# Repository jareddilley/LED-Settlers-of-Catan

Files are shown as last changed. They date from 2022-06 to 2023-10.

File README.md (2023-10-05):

# SMART-Catan-Game-Board


Fully 3D printed 2-4 person Catan board with corresponding LED tiles, electronic rolling with place pointers, recourse summary display, and all in a battery-powered sealed package. This project is powered by a rechargeable 9V battery and an Arduino nano to minimize its footprint. Above is a demo of the rolling animation that is done at the touch of a button. When clicked a random number generator is used to roll the dice with the same probability of rolling numbers that two regular dice do. Once rolled the number will be displayed on the seven-segment display and the corresponding locations will be singled out and lit up. This fixes one of the common issues of Catan where you roll the dice and try to figure out who gets what.

Built with the Open Source mindset allowing other people to build it at home with a 3D printer (I used an Ender 3 Pro) with a choice of soldier or using a breadboard. 

Attached is the Fusion 360 so the models can be edited directly and used to better understand how it is broken down. A YouTube link for visual learners: https://www.youtube.com/watch?v=NJuYirOUeOg&t=12s&ab_channel=JaredDilley

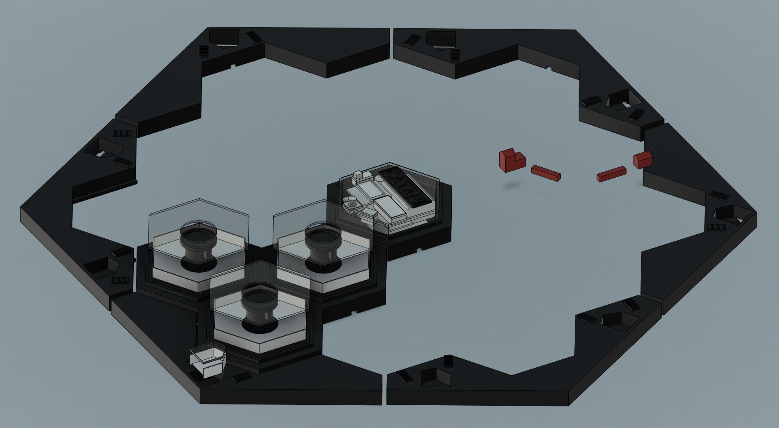
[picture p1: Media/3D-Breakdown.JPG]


Below is the full Arduino schematic for anyone trying to build the project. For those who want a closer look, the diagram can be found in the Fritzing Schematic folder. If there are any confusions feel free to ask in the discussion.

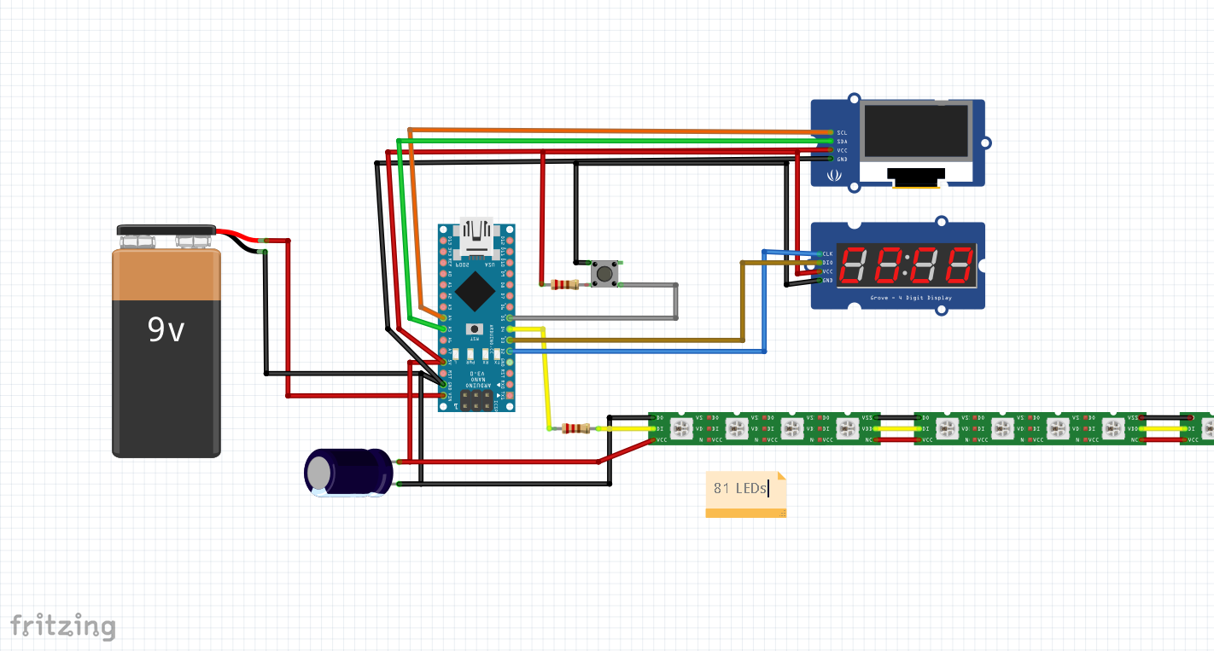
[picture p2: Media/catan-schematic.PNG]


# Board Generation


When the board is powered on the tiles are randomly set up in an instant. I know some people like to play an evenly distributed board, but it can be added as a feature in the second version. The instant setup of the board was the main issue I wanted to fix with this project. Whenever you want to play a game of Catan it always takes time to set up the board. Here it can be set up instantly with the flick of a switch.

# Info Display


With the Arduino micro powering the board I figured I would add additional info that can be tracked on displays. In the middle of the board lies the power center that doubles as the desert tile. Here you can find a seven-segment display that serves as a remembrance for what was previously rolled to the next player. In V2 this could also serve as a time for those who take too long on their turn. In addition, there sits an OLED display that stores the number of rolls that each resource has been rolled. This can help judge the board for what resources might be in short supply and makes for cool stats to look at, at the end of the game. 



# Bonus


The light-up hexagons make a game night in the dark that much cooler.

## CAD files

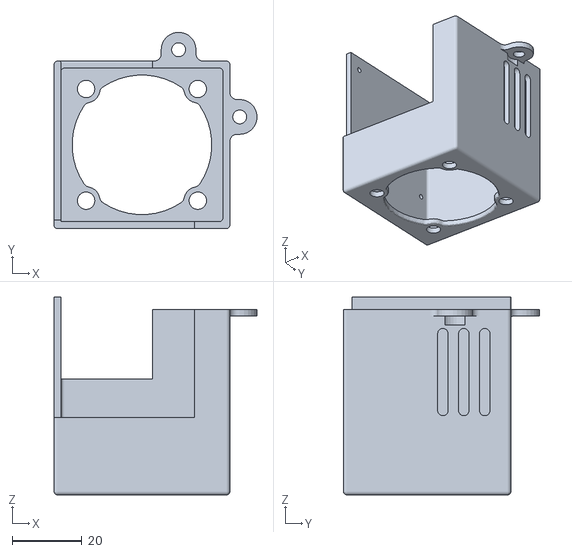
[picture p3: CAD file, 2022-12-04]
Print files/V2.stl
58.2 x 56.2 x 56.7

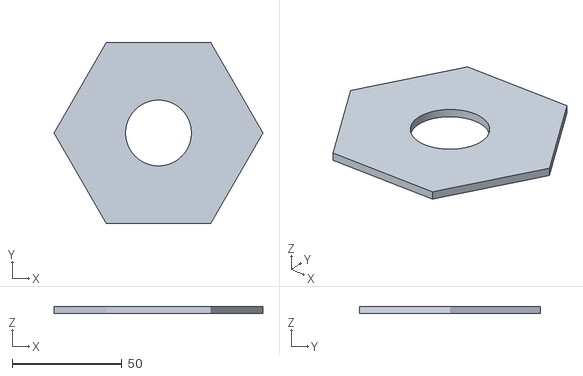
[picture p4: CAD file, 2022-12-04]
Print files/Diffuser Panel.stl
95.2 x 82.5 x 3.17

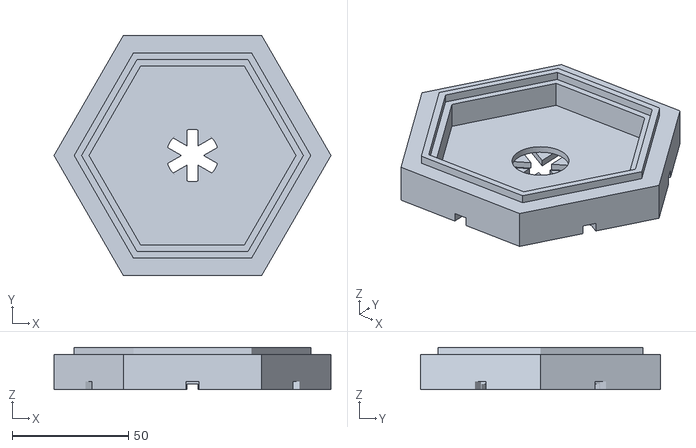
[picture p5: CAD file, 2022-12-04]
Print files/Split Board v2.stl
118.9 x 103.0 x 18.2

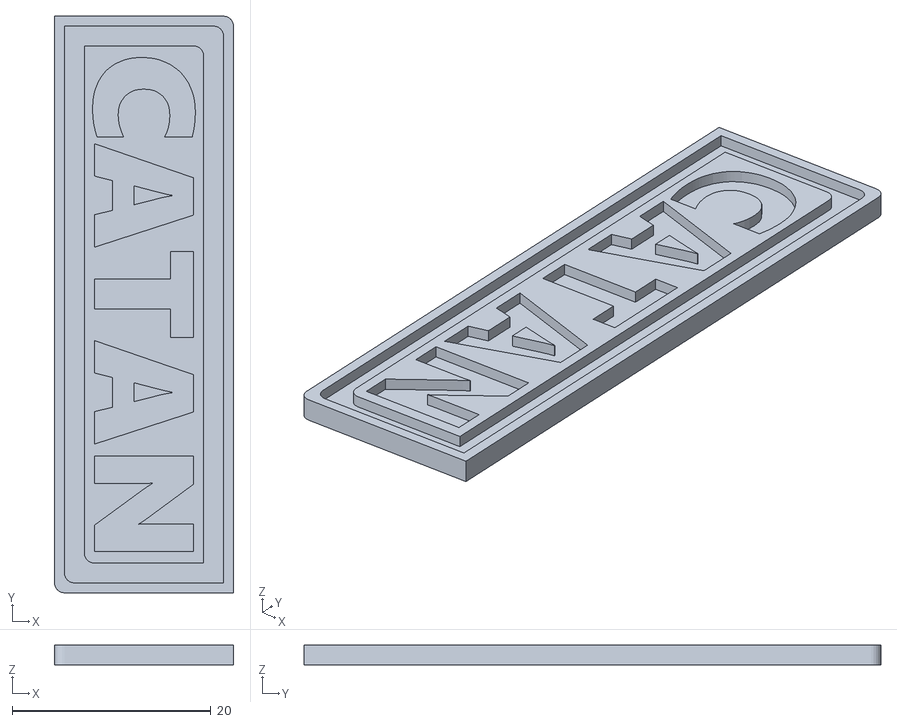
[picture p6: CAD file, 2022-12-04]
Print files/Decal.stl
18.0 x 58.0 x 2.00

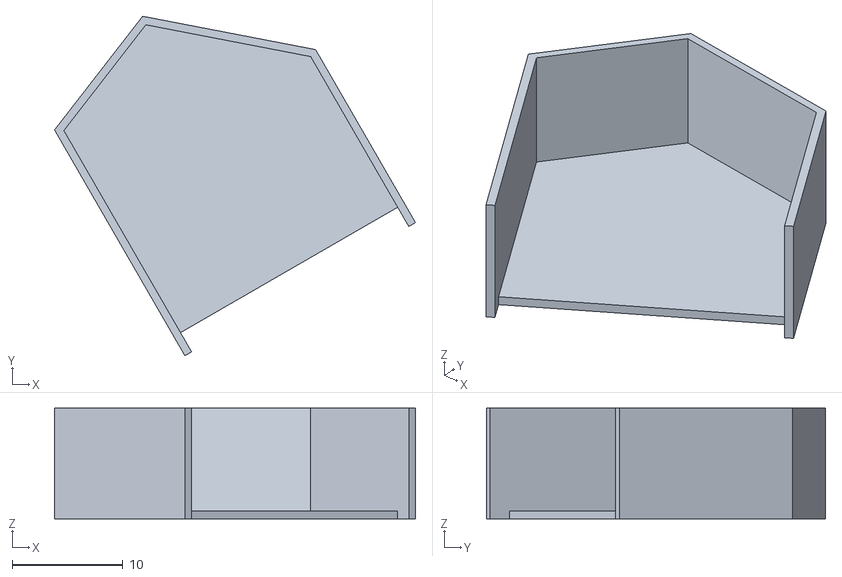
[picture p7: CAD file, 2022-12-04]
Print files/boat refector.stl
32.5 x 30.6 x 10.0

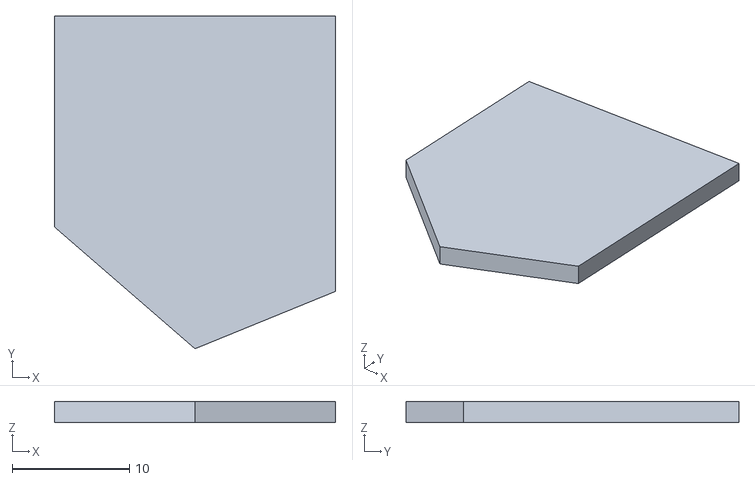
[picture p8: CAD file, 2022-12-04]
Print files/Boat diffuser.stl
24.0 x 28.4 x 1.80

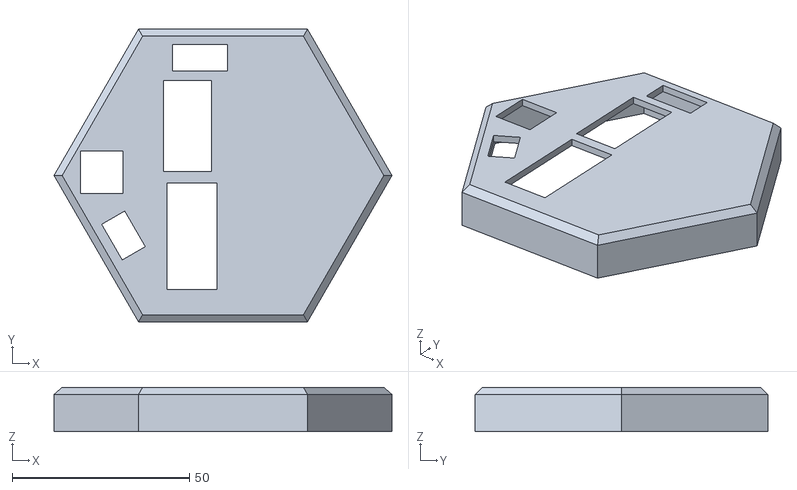
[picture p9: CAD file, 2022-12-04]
Print files/cover.stl
95.2 x 82.5 x 12.5

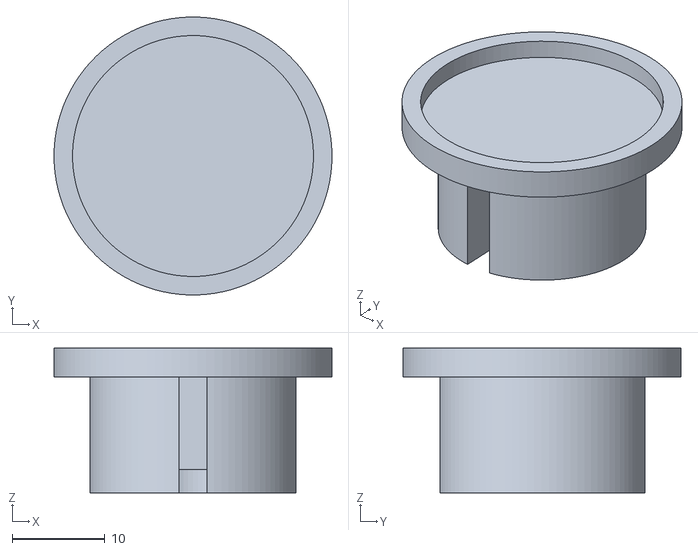
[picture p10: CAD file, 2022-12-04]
Print files/Center Platform v2.stl
30.0 x 30.0 x 15.6

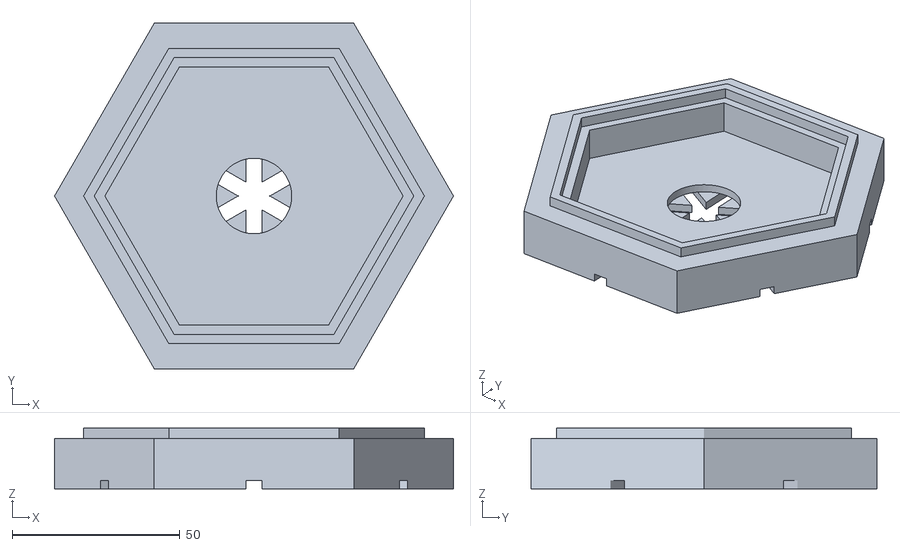
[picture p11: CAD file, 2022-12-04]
Print files/Split Board.stl
118.9 x 103.0 x 18.2

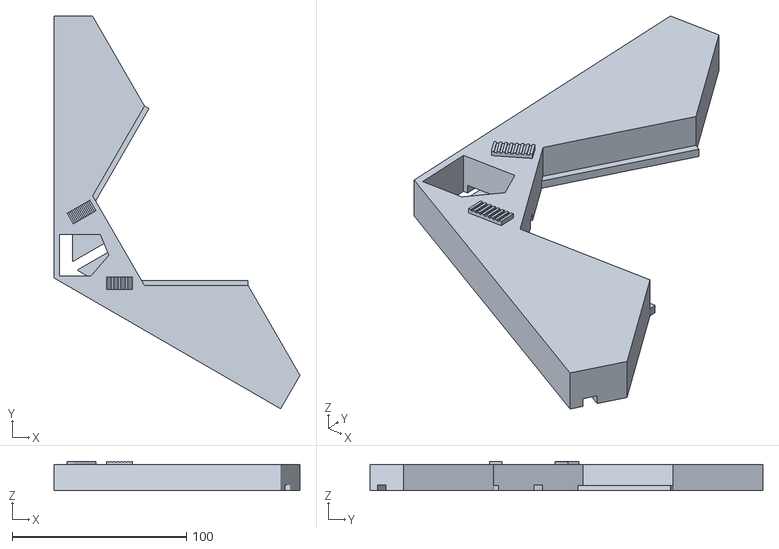
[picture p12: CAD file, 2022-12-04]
Print files/boarder 1.stl
141.1 x 225.2 x 16.8

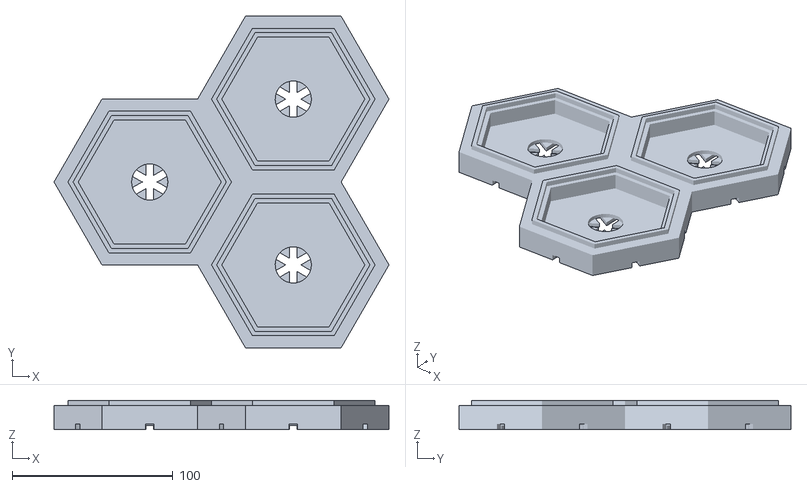
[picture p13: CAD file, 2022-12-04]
Print files/Split Board 3x.stl
208.1 x 206.0 x 18.2

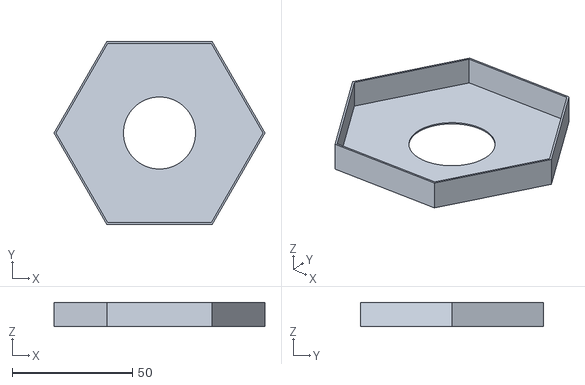
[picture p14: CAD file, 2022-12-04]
Print files/reflector V2.stl
87.9 x 76.1 x 10.0

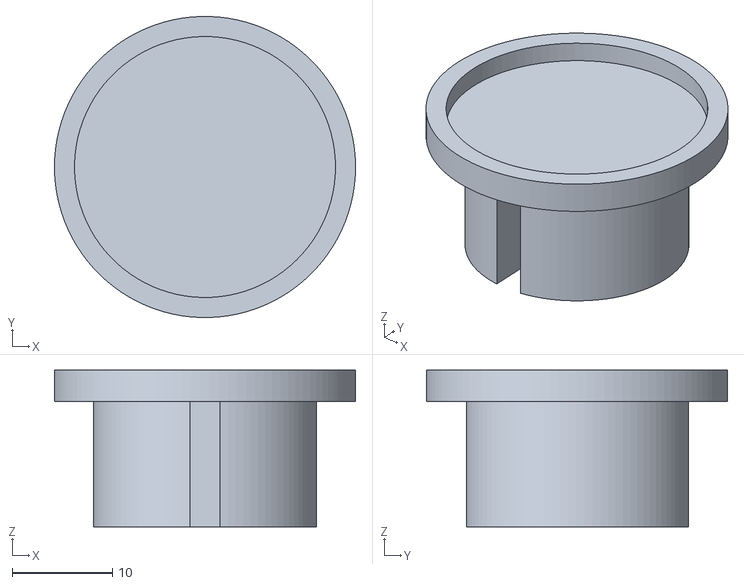
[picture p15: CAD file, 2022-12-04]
Print files/Center Platform.stl
30.0 x 30.0 x 15.6

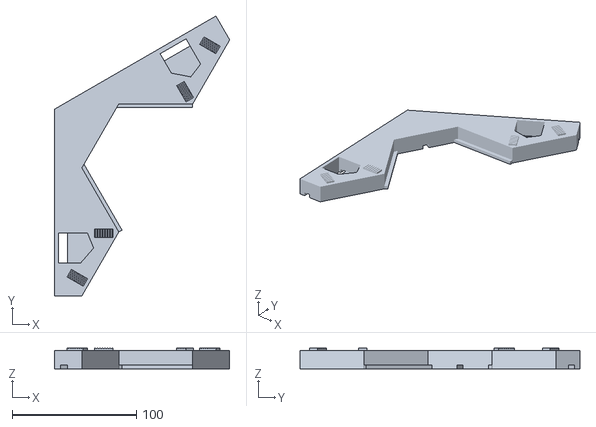
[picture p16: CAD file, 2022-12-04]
Print files/boarder 2.stl
141.1 x 225.2 x 16.8

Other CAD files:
Print files/reflector.stl

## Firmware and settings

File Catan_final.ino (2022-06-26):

#include <FastLED.h>
#include <TM1637.h>
#include <MsTimer2.h>
#include <SPI.h>
#include <Wire.h>
#include <Adafruit_GFX.h>
#include <Adafruit_SSD1306.h>

#define NUM_LEDS  81
#define spotSize  4
#define LED_PIN   4
#define Button  5
int brightness = 20;
const int range = 18;
boolean clicked = false;
int tracker = 0;
unsigned long now = millis();
int CLK = 2;
int DIO = 3;
TM1637 tm(CLK,DIO);
Adafruit_SSD1306 display(-1);
int brick = 0; 
int wheat = 0; 
int wood = 0; 
int rock = 0; 
int sheep = 0;


// Brick::Red, Boulder::Cyan, Logs::Green, Hay::Orange, Sheep::white, Desert::Black
uint32_t resource[range] = {CRGB::Red,CRGB::Red,CRGB::Red,CRGB::Cyan,CRGB::Cyan,CRGB::Cyan,
CRGB::Green,CRGB::Green,CRGB::Green,CRGB::Green,CRGB::Orange,CRGB::Orange,CRGB::Orange,CRGB::Orange,
CRGB::White,CRGB::White,CRGB::White,CRGB::White};
CRGB all[5] = {CRGB::Red,CRGB::Green,CRGB::Orange,CRGB::Cyan,CRGB::White};
//int temp[range] = {5,2,6,3,8,10,9,12,11,4,8,10,9,4,5,6,3,11};
int values[range] = {11,3,6,5,4,9,10,8,4,11,12,9,10,8,3,6,2,5};
int spotValues[range];
CRGB leds[NUM_LEDS];
CRGB currentColors[range];

void setSpot (int spot, CRGB color, boolean save){  
    int currentLED = (spot - 1)*spotSize;
    int lastLED = currentLED + spotSize; 
    for (currentLED; currentLED < lastLED; currentLED++) {   
      leds[currentLED] = color;
    }
    if (save){
      currentColors[spot-1] = color; 
    }
}

boolean arrayIncludeElement(int randArray[], int input, int range) {
  for (int i = 0; i < range; i++) {   
    if (randArray[i] == input) {
      return true;
    }
  }
  return false;
}

void rollDice() {
  // Roll dice
  // randomSeed(analogRead(0));
  int roll = random(1,7) + random(1,7);
  tm.init(); // clear
  if (roll < 10){
    tm.display(3,roll);
  } else{
    tm.display(2,1);
    tm.display(3,roll-10);
  }
  // show dice value
  for (int i = 0; i < range; i++) {   
    setSpot(i+1, CRGB::Black, false);
  }
  FastLED.show();  
  for (int i = range-1; i >= (range-roll); i--) {   
    setSpot(i+1, CRGB::White, false);
    FastLED.show();
    delay(100);
  }
  delay(500);
  // show only spots with that roll
  int locations[range];
  int count = 0;
  if (roll == 7){
    for (int a = 0; a < 3; a++) {
      for (int i = 0; i < range; i++) {   
        setSpot(i+1, CRGB::Red, false);
      }
      FastLED.show();
      delay(500);
      if (a < 2){
        for (int i = 0; i < range; i++) {   
          setSpot(i+1, CRGB::Black, false);
        }
        FastLED.show();
        delay(500);
      }
    }
  } else{
    for (int i = 0; i < range; i++) {   
      if (values[i] == roll){
        setSpot(i+1, currentColors[i], false);
        if (currentColors[i] == all[0]){
          brick++;
        }
        if (currentColors[i] == all[1]){
          wood++;
        }
        if (currentColors[i] == all[2]){
          wheat++;
        }
        if (currentColors[i] == all[3]){
          rock++;
        }
        if (currentColors[i] == all[4]){
          sheep++;
        }
      }
      else{
        setSpot(i+1, CRGB::Black, false);
      }
    }
    updateDisplay(brick, wheat, wood, rock, sheep);
    FastLED.show();
    //delay(5000);
    for (int i = 0; i < 4; i++){
      leds[72] = all[i];
      leds[73] = all[i];
      leds[76] = all[i];
      leds[79] = all[i];
      FastLED.show(); 
      delay(1500);
    }
  }
  // updateDisplay(brick, wheat, wood, rock, sheep);
  // reset board
  for (int i = 0; i < range; i++) {   
    setSpot(i+1, currentColors[i], true);
  }
  FastLED.show();
}

void updateDisplay(int brick, int wheat, int wood, int rock, int sheep){
  display.clearDisplay();
  display.setCursor(0, 0);
  display.println("Brick: " + String(brick));
  display.setCursor(0, 10);
  display.println("Wheat: " + String(wheat));
  display.setCursor(0, 20);
  display.println("Sheep: " + String(sheep));
  display.setCursor(70, 0);
  display.println("Wood: " + String(wood));
  display.setCursor(70, 10);
  display.println("Rock: " + String(rock));
  display.display();
}


void setup() {
   // set up display
  display.begin(SSD1306_SWITCHCAPVCC, 0x3C);
  display.clearDisplay();
  display.setTextSize(1);
  display.setTextColor(WHITE);
  display.setCursor(0, 0);
  updateDisplay(brick, wheat, wood, rock, sheep);
  // put your setup code here, to run once:
  tm.init();
  // set brightness; 0-7
  tm.set(1);
  pinMode(Button, INPUT);
  FastLED.addLeds<WS2812B, LED_PIN, GRB>(leds, NUM_LEDS);
  FastLED.setBrightness(brightness);
  leds[74] = CRGB::Red;
  leds[75] = CRGB::Green;
  leds[77] = CRGB::Orange;
  leds[78] = CRGB::Cyan;
  leds[80] = CRGB::White;

  // set up random board 
  randomSeed(analogRead(0));
  int first = random(range);
  int randArray[range] = {first};
  int num = 1;
  while(num < range){
    int input = random(range);
    if (!arrayIncludeElement(randArray, input, num)){
      randArray[num] = input;
      
      num++;
    }
  }
  for (int i = 0; i < range; i++) {   
    setSpot(i + 1, resource[randArray[i]], true);
  }
}

void loop() { 
  if (tracker >= 5){
     tracker = 0;
  }
  if(millis() >= (now + 1500)){
    leds[72] = all[tracker];
    leds[73] = all[tracker];
    leds[76] = all[tracker];
    leds[79] = all[tracker];
    FastLED.show(); 
    tracker++;
    Serial.println(tracker);
    now = millis();
  }
   
  int ButtonState = digitalRead(Button);

  if (ButtonState == HIGH){ // clicked
    clicked = true;   
  }

  if (clicked == true){
    delay(250);
    rollDice();
    clicked = false;     
  }

}
